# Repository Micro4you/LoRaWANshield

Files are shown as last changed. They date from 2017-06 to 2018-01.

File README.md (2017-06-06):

# RN2483shield

KiCad design for an Arduino compatible RN2483 (or RN2903) LoRaWAN shield.

Fork of the original [jpmeyers/RN2483shield](https://github.com/jpmeijers/RN2483shield).

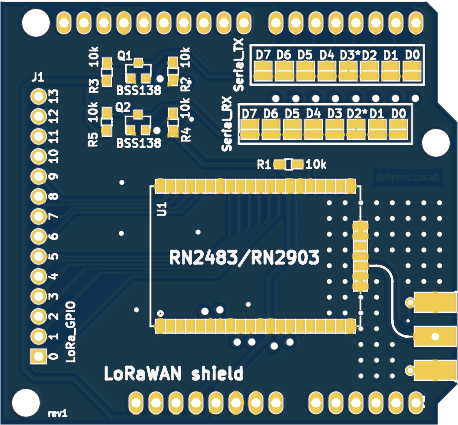
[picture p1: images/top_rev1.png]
top layout

***Top board view***

Adjusted to:

 * use the Microchip specified RF trace geometry to maintain R&TTE (CE) and FCC testing compliance for the radio module (datasheet pg. 12),
 * ignore the 433MHz antenna trace (868MHz only),
 * use solder jumper connections for Serial UART connection,
 * normally connected jumpers for default connections:
   * Serial D3 Tx → Radio Serial Rx,
   * Serial D2 Rx → Radio Serial Tx,
 * Mosfet level converters on the UART connection to allow 5V→3.3V signal conversion,
 * Breakout of all GPIO pins on the radio (GPIO 0–13),
 * edge mounted SMA connetion for antenna.

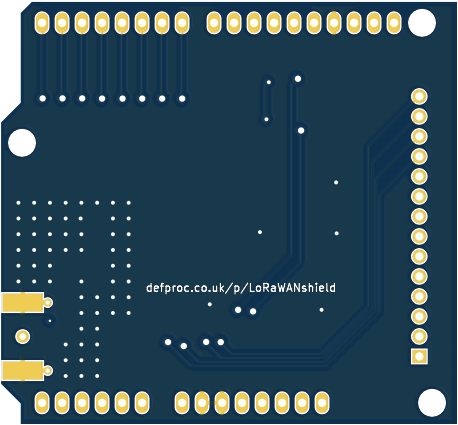
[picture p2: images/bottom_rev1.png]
bottom layout

***Bottom board view***

## Required Parts

 * 1× Shield PCB,
 * 2× BSS138 SOT-23 N-channel MOSFET,
 * 5× 0603 10k resistors,
 * 1× SMA female edge jack,
 * 1× SMA 868MHz antenna,
 * 1× 1x10 stacking thru-headers,
 * 2× 1x8 stacking thru-headers,
 * 1× 1x6 stacking thru-headers

## Setting the Serial lines

By default, the Arduino D3 (Serial Tx) is connected to the Radio UART_RX, and the Arduino D2 (Serial Rx) is connected to the Radio UART_TX. By cutting between the pads marked by an asterisk in the Serial_TX and Serial_RX bank, these links can be severed, and a new connection made for each UART line by adding solder to bridge one pair of solder jumpers for each direction.

Only make connetions across one of each direction at a time to prevent multiplexing the digital pins on the Arduino, and don't connect both TX and RX to the same pin, as this will make communication very difficult!

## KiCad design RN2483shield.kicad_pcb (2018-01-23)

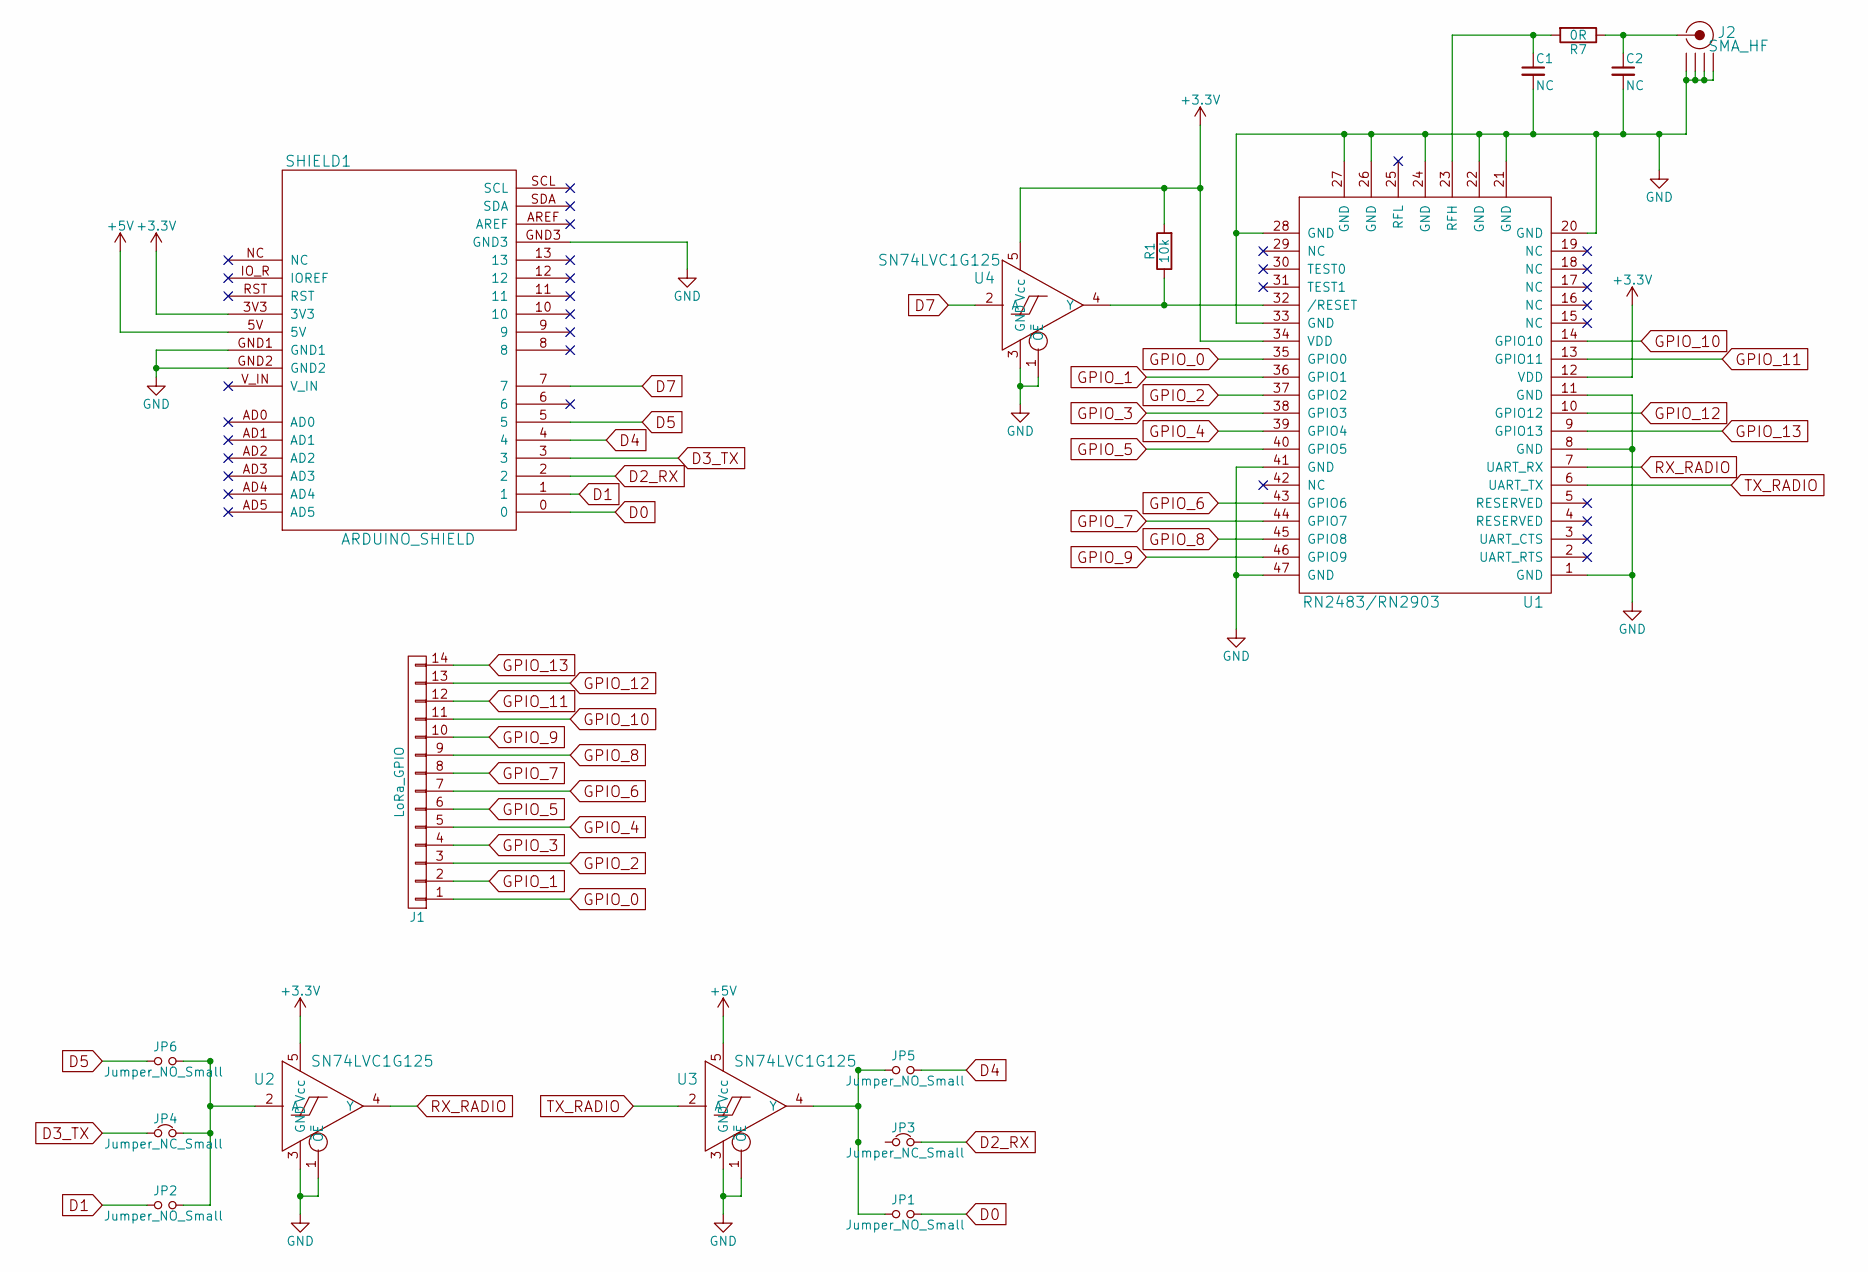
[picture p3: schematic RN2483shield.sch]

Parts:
C1, C2: NC; R_0603
J1: LoRa_GPIO; CONN_1x14
J2: SMA_HF; multi-rf-sma-ufl
JP1, JP2, JP5, JP6: Jumper_NO_Small; NO_SMD_JPR
JP3, JP4: Jumper_NC_Small; NC_SMD_JPR
R1: 10k; R_0603
R7: 0R; R_0603
SHIELD1: ARDUINO_SHIELD; ARDUINO_SHIELD_NOICSP
U1: RN2483/RN2903; RN2483
U2, U3, U4: SN74LVC1G125; SOT-23-5

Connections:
+3V3: R1.2, SHIELD1.3V3, U1.12 (VDD), U1.34 (VDD), U2.5 (Vcc), U4.5 (Vcc)
+5V: SHIELD1.5V, U3.5 (Vcc)
D0: JP1.2, SHIELD1.0
D1: JP2.2, SHIELD1.1
D2_RX: JP3.2, SHIELD1.2
D3_TX: JP4.2, SHIELD1.3
D4: JP5.2, SHIELD1.4
D5: JP6.2, SHIELD1.5
D7: SHIELD1.7, U4.2 (A)
GND: C1.2, C2.2, J2.2 (GND1), SHIELD1.GND1, SHIELD1.GND2, SHIELD1.GND3, U1.1 (GND), U1.8 (GND), U1.11 (GND), U1.20 (GND), U1.21 (GND), U1.22 (GND), U1.24 (GND), U1.26 (GND), U1.27 (GND), U1.28 (GND), U1.33 (GND), U1.41 (GND), U1.47 (GND), U2.1 (ŌĒ), U2.3 (GND), U3.1 (ŌĒ), U3.3 (GND), U4.1 (ŌĒ), U4.3 (GND)
GPIO_0: J1.1, U1.35 (GPIO0)
GPIO_1: J1.2, U1.36 (GPIO1)
GPIO_2: J1.3, U1.37 (GPIO2)
GPIO_3: J1.4, U1.38 (GPIO3)
GPIO_4: J1.5, U1.39 (GPIO4)
GPIO_5: J1.6, U1.40 (GPIO5)
GPIO_6: J1.7, U1.43 (GPIO6)
GPIO_7: J1.8, U1.44 (GPIO7)
GPIO_8: J1.9, U1.45 (GPIO8)
GPIO_9: J1.10, U1.46 (GPIO9)
GPIO_10: J1.11, U1.14 (GPIO10)
GPIO_11: J1.12, U1.13 (GPIO11)
GPIO_12: J1.13, U1.10 (GPIO12)
GPIO_13: J1.14, U1.9 (GPIO13)
unnamed: C1.1, R7.2, U1.23 (RFH)
unnamed: C2.1, J2.1 (RF), R7.1
unnamed: JP1.1, JP5.1, U3.4 (Y)
unnamed: JP2.1, JP4.1, JP6.1, U2.2 (A)
unnamed: R1.1, U1.32 (/RESET), U4.4 (Y)
RX_RADIO: U1.7 (UART_RX), U2.4 (Y)
TX_RADIO: U1.6 (UART_TX), U3.2 (A)

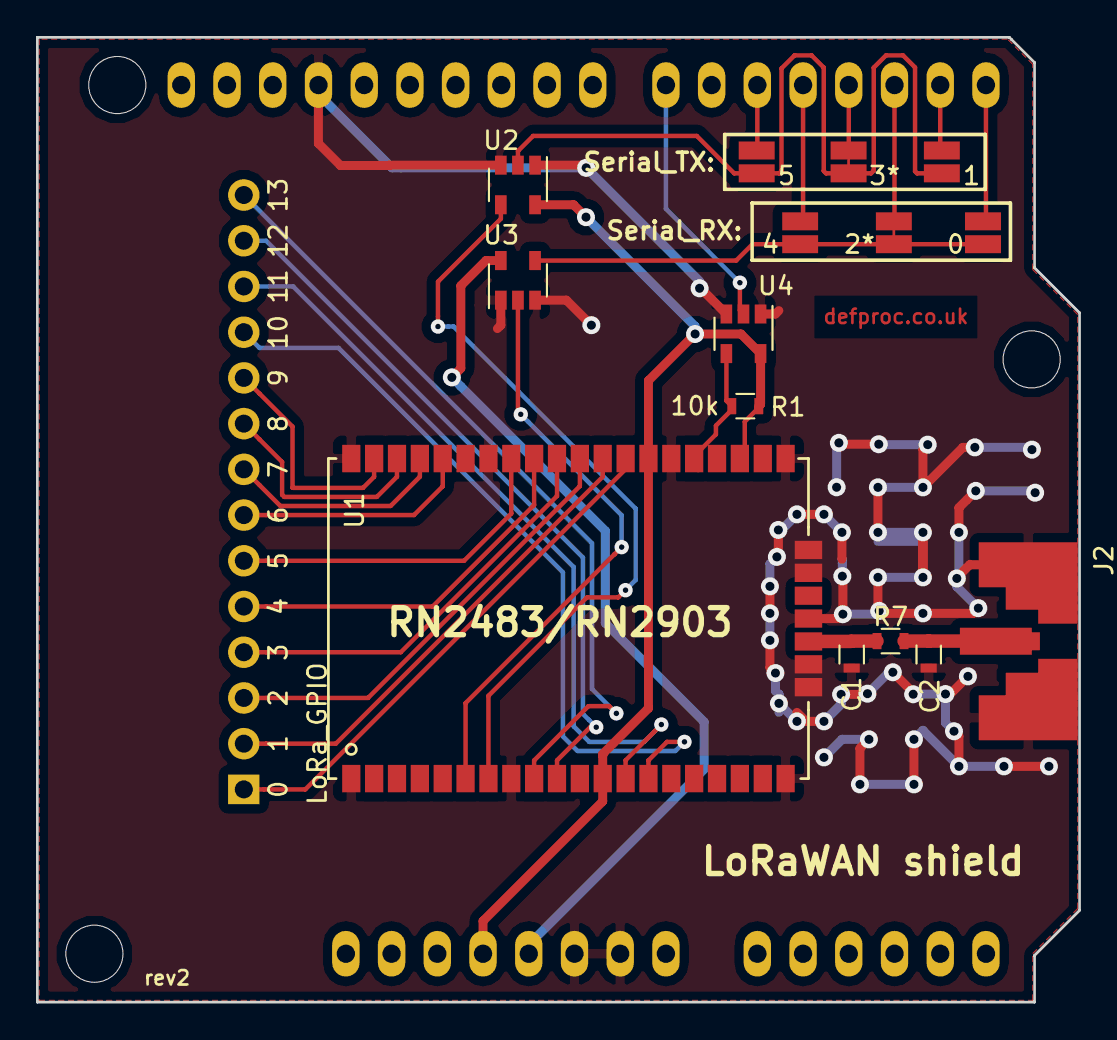
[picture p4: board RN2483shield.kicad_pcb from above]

Board: 2 copper layers, 57.9 x 53.6 mm, 17 parts (0 on the bottom side), 31 nets.

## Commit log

2017-06-05 redraft of shield
    [RN2483shield.sch]
2017-06-05 redrafted the board with edgeSMA, gpio breakouts and solderpad serial connections
    [RN2483shield.kicad_pcb, RN2483shield.sch]
2017-06-05 and with title, link, revision and makers mark
    [RN2483shield.kicad_pcb]
2017-06-05 and remove the soldermask from the solder jumpers
    [RN2483shield-B.Cu.gbl, RN2483shield-B.Mask.gbs, RN2483shield-B.Paste.gbp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]
2017-06-05 removed freetronics libraries
    [RN2483shield.sch]
2017-06-06 removed sheet ref from gerbers and included board renders
    [RN2483shield-B.Cu.gbl, RN2483shield-B.Mask.gbs, RN2483shield-B.Paste.gbp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]
2018-01-23 EOD: redrafted board with new level shifters
    [RN2483shield.kicad_pcb, RN2483shield.sch]
